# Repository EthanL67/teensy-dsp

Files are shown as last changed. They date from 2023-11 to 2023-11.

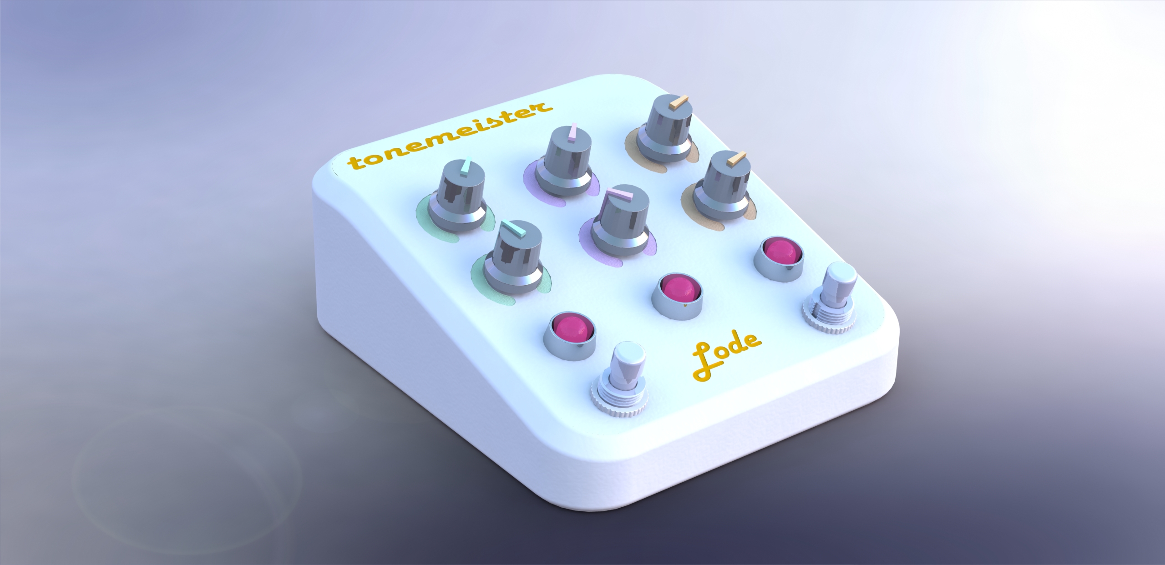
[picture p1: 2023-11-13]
renders/corner.JPG

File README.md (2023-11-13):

# teensy-dsp
Experimental pedal-format stereo effects processor using the Teensy 4.1 and Audio Shield. Hardware development currently in progress!

corner


My design goals are as follows:
-	Reprogrammable stereo multi-effects console
-	Accepts instrument-level and line-level audio inputs
-	Runs on common 9V guitar pedal power supplies
-	Implementations of common audio effects:
    -	Saturation/distortion, fuzz
    -	Phaser, vibrato, chorus
    -	Digital delay, tape delay emulation
    -	Studio-quality reverb

# BOM
- [Teensy 4.1 Microcontroller](https://www.pjrc.com/store/teensy41.html)
- [Teensy Audio Shield](https://www.pjrc.com/store/teensy3_audio.html)

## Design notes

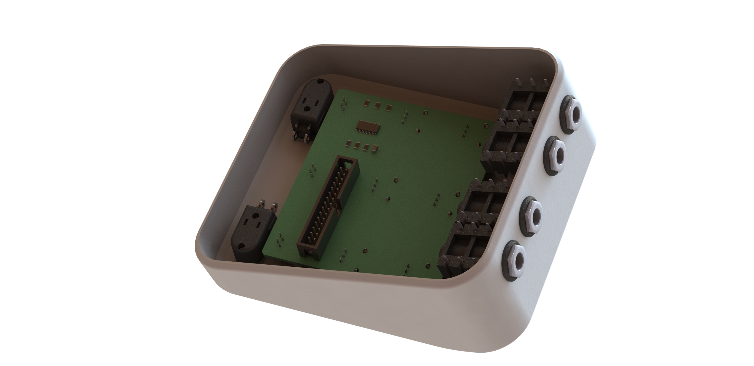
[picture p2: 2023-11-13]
renders/back.JPG

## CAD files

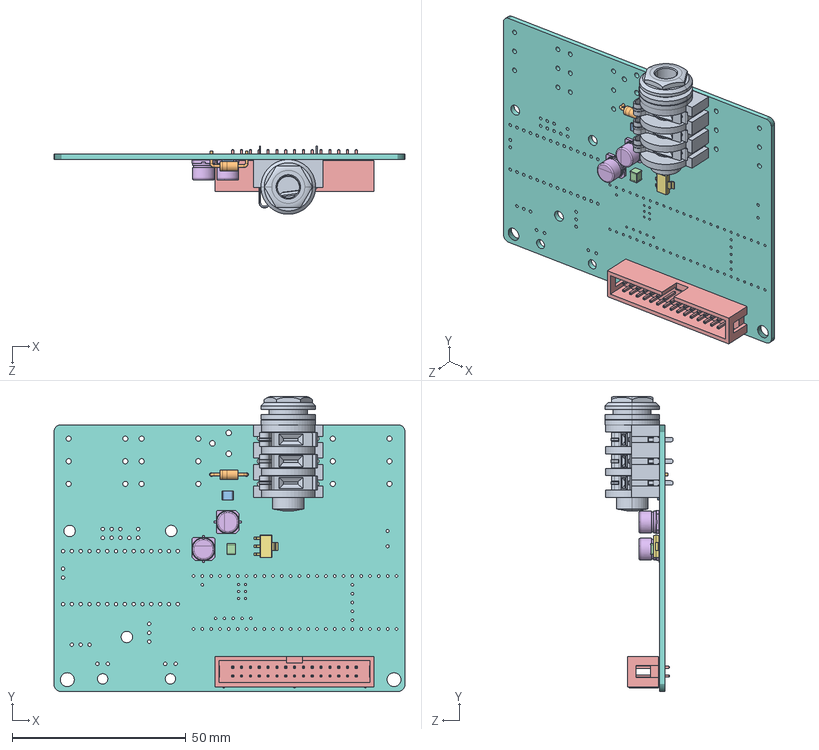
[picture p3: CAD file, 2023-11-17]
pcb/teensy-dsp/teensy-dsp-pcb.SLDASM
101.0 x 84.9 x 19.7 mm
AutoRecover Of COMPOUND.step.SLDPRT.swar
SOLID.step
SOLID-0.step
SOLID-1.step
SOLID-2.step
SOLID-3.step x 2
SOLID-4.step
AutoRecover Of PCB.step.SLDPRT.swar

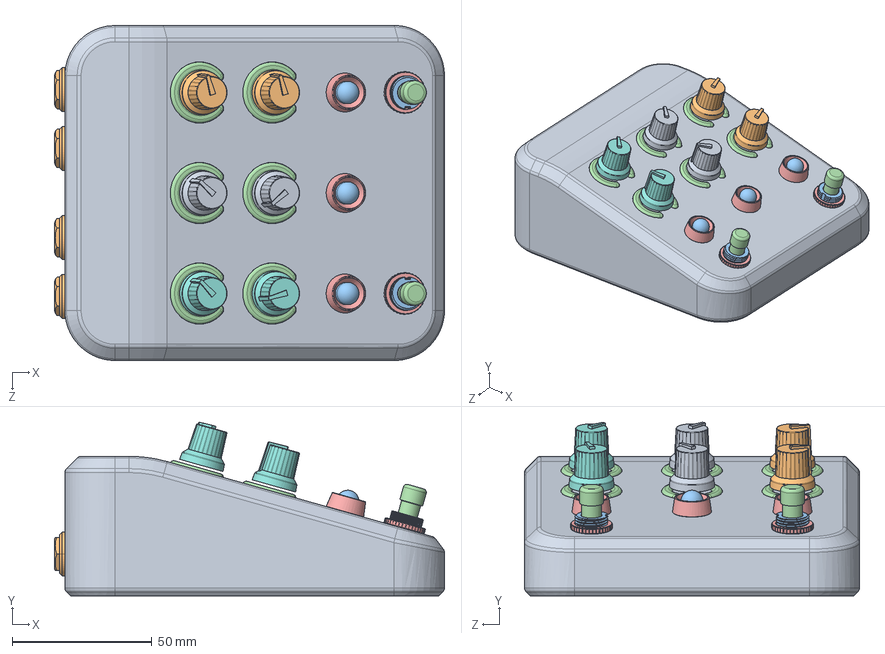
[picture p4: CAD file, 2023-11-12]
case/Case.SLDASM
139.7 x 62.2 x 120.0 mm
case-lid
ACJS-IH.STEP x 4
Momentary footswitch1.step x 2
Momentary footswitch6.step x 2
PLH-8 LED holder - body x 3
PLH-8 LED holder - spacer x 3
PLH-8 LED holder - nut x 3
CL170849BR x 2
CL170851BR x 2
CL170853BR x 2
LED-8mm x 3
knob-inlay x 6
M12x1 knurled thumb nut x 2

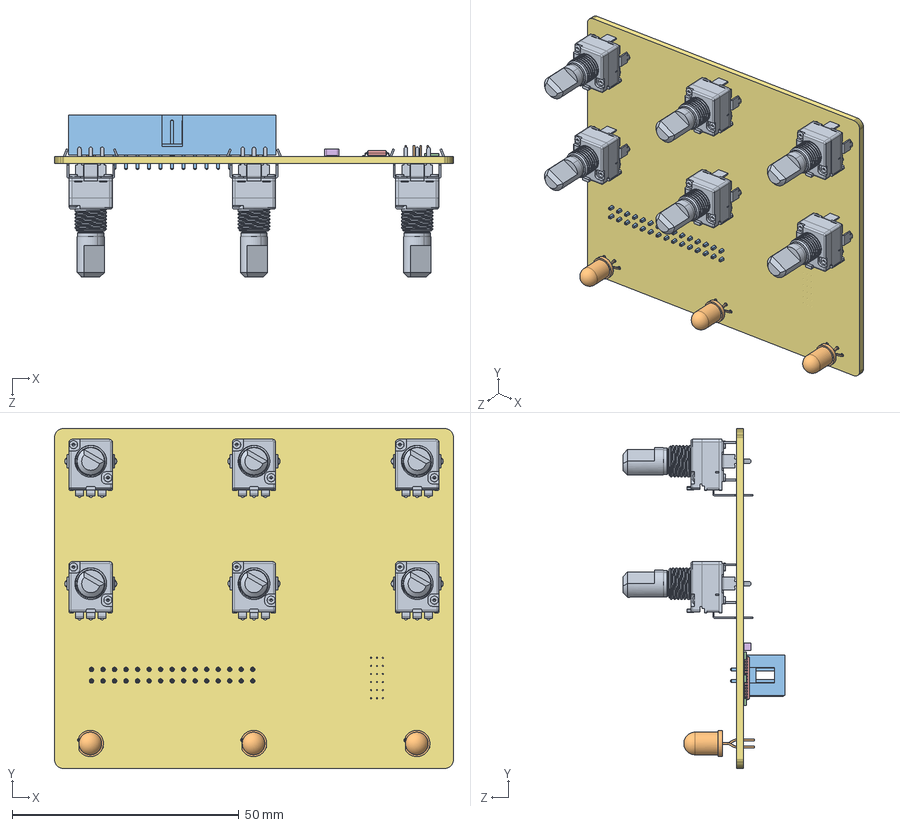
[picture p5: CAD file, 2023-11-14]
pcb/teensy-dsp/teensy-dsp-frontend/teensy-dsp-frontend.SLDASM
88.0 x 75.0 x 35.8 mm
COMPOUND.step x 6
SOLID.step x 3
SOLID-0.step
SOLID-1.step x 6
SOLID-2.step
SOLID-3.step
PCB.step

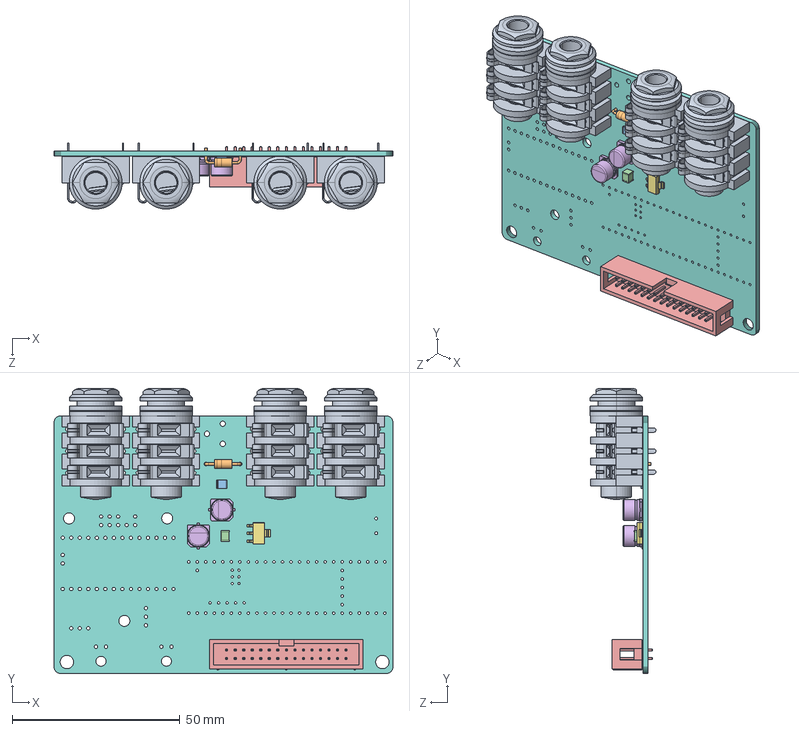
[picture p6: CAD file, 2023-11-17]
pcb/teensy-dsp/teensy-dsp.SLDASM
101.0 x 84.9 x 19.7 mm
COMPOUND.step x 4
SOLID.step
SOLID-0.step
SOLID-1.step
SOLID-2.step
SOLID-3.step x 2
SOLID-4.step
PCB.step

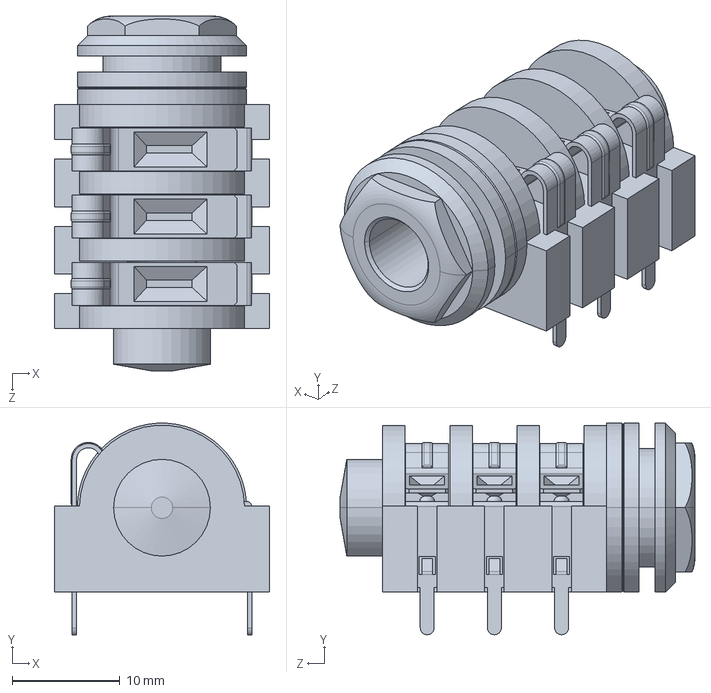
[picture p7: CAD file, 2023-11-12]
case/ACJS-IH--3DModel-STEP-56544.SLDASM
20.0 x 19.7 x 33.0 mm

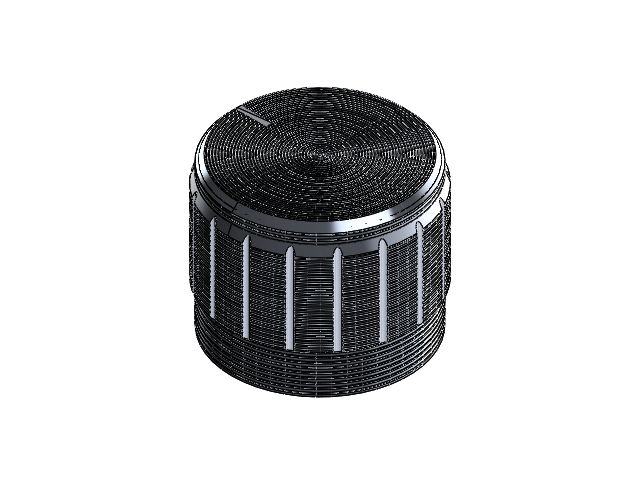
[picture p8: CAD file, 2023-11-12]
case/knob.SLDASM
__ 20 outtt.STEP
__ 20 innerrr.STEP

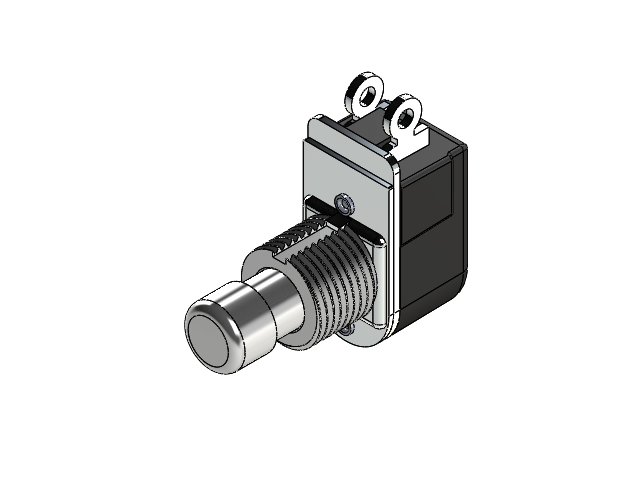
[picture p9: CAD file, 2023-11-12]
case/Momentary footswitch.step.SLDASM
Momentary footswitch1.step
Momentary footswitch2.step
Momentary footswitch3.step
Momentary footswitch4.step
Momentary footswitch5.step
Momentary footswitch6.step
Momentary footswitch7.step
Momentary footswitch8.step
Momentary footswitch9.step

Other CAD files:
pcb/teensy-dsp/teensy-dsp-frontend/IDC-Header_2x15_P2.54mm_Vertical.step.SLDASM
pcb/teensy-dsp/CP_Elec_6.3x5.9.step.SLDASM
pcb/teensy-dsp/IDC-Header_2x15_P2.54mm_Vertical.step.SLDASM
pcb/teensy-dsp/teensy-dsp-frontend/HTSSOP-28-1EP_4.4x9.7mm_P0.65mm_EP3.4x9.5mm.step.SLDASM
pcb/teensy-dsp/teensy-dsp-frontend/R_1206_3216Metric.step.SLDASM
pcb/teensy-dsp/teensy-dsp-frontend/C_1206_3216Metric.step.SLDASM
pcb/teensy-dsp/C_1210_3225Metric.step.SLDASM
pcb/teensy-dsp/teensy-dsp-frontend/P0915N-FC15AR50K.step.SLDASM
pcb/teensy-dsp/D_DO-41_SOD81_P10.16mm_Horizontal.step.SLDASM
pcb/teensy-dsp/R_1210_3225Metric.step.SLDASM
pcb/teensy-dsp/SOT-223.step.SLDASM
case/57GB5FX--3DModel-STEP-1.SLDPRT
case/CL170849BR.SLDPRT
case/CL170851BR.SLDPRT
case/CL170853BR.SLDPRT
case/LED-8mm.SLDPRT
case/M12x1 knurled thumb nut.SLDPRT
case/Momentary footswitch1.step.SLDPRT
case/Momentary footswitch2.step.SLDPRT
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

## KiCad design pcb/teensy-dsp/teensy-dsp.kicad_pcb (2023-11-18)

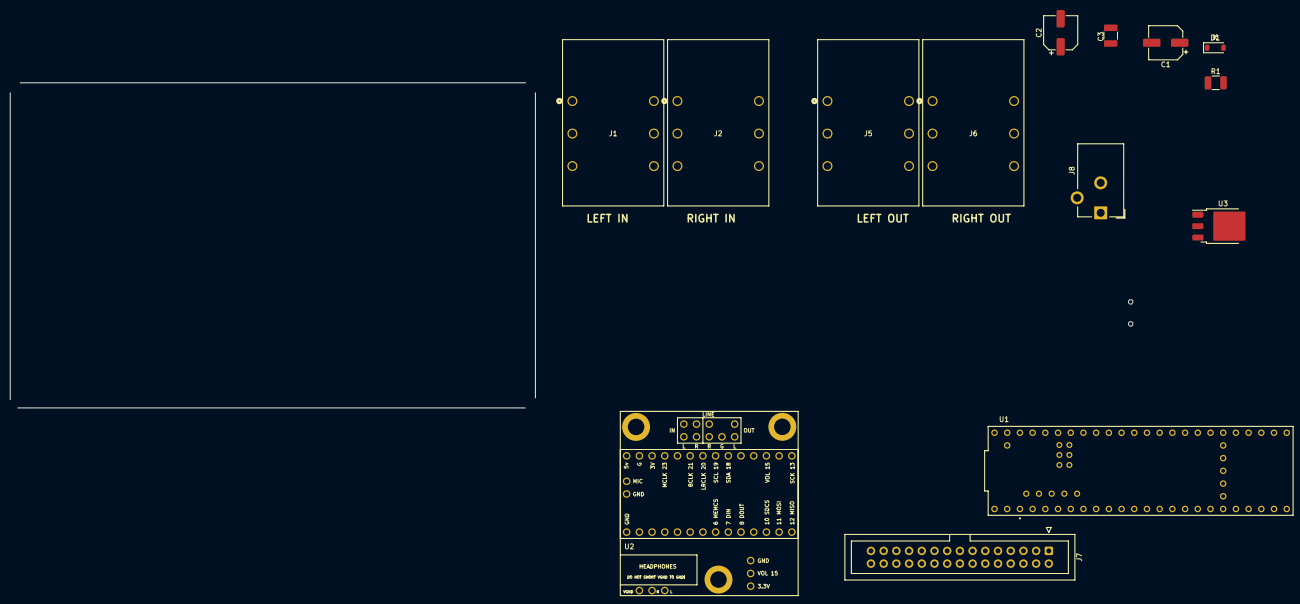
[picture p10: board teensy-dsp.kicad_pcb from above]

Board: 4 copper layers, 105.0 x 65.0 mm, 15 parts (1 on the bottom side), 37 nets, no tracks yet.

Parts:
C1, C2: 100u 16V; CP_Elec_6.3x5.9
C3: 100n 16V; C_1210_3225Metric_Pad1.33x2.70mm_HandSolder
D1: D; D_SOD-123
J1, J2, J5, J6: ACJS-IH; ACJS-IH_AMP
J7: Conn_02x15_Odd_Even; IDC-Header_2x15_P2.54mm_Vertical
J8: Barrel_Jack_Switch; BarrelJack_CUI_PJ-102AH_Horizontal
J9: USB_B_Mini; USB_Mini-B_Wuerth_65100516121_Horizontal
R1: 47R; R_1210_3225Metric_Pad1.30x2.65mm_HandSolder
U1: Teensy4.1; MODULE_DEV-16771
U2: Teensy4.0_AudioShield_REVD; 4.0audioshield
U3: LM7805_TO220; TO-252-3_TabPin2

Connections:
+3.3V: J7.3, U1.3.3V_1 (3.3V), U1.3.3V_2 (3.3V__1), U1.3.3V_3 (3.3V__2), U2.28 (3V)
+5V: C2.1, C3.1, U1.VIN, U3.3 (VO)
+9V: C1.1, J7.1, R1.2, U3.1 (VI)
Audio BCLK: U1.21 (A7), U2.25 (21_A7_RX5_BCLK1)
Audio DIN: U1.7 (RX2), U2.9 (7_RX2_OUT1A)
Audio DOUT: U1.8 (TX2), U2.10 (8_TX2_IN1)
Audio LRCLK: U1.20 (A6), U2.24 (20_A6_TX5_LRCLK1)
Audio MCLK: U1.23 (A9), U2.27 (23_A9_CRX1_MCLK1)
Audio MEMCS: U1.6 (OUT1D), U2.8 (6_OUT1D)
Audio MISO: U1.12 (MISO), U2.14 (12_MISO_MQSL)
Audio MOSI: U1.11 (MOSI), U2.13 (11_MOSI_CTX1)
Audio SCK: U1.13 (SCK), U2.17 (13_SCK_CRX1_LED)
Audio SCL: U1.19 (A5), U2.23 (19_A5_SCL0)
Audio SDA: U1.18 (A4), U2.22 (18_A4_SDA0)
Audio SDCS: U1.10 (CS1), U2.12 (10_CS_MQSR)
FSW_1: J7.7, U1.28 (RX7)
FSW_2: J7.5, U1.29 (TX7)
GND: C1.2, C2.2, C3.2, J1.R, J2.R, J5.R, J6.R, J7.2, J7.4, J7.6, J7.8, J7.10, J7.12, J7.14, J7.16, J7.18, J7.20, J7.22, J7.24, J7.26, J7.28, J7.30, J8.1, J9.5 (GND), U1.GND1 (GND), U1.GND2 (GND__1), U1.GND3 (GND__2), U1.GND4 (GND__3), U1.GND5 (GND__4), U1.USB_GND1 (USB_GND), U1.USB_GND2 (USB_GND__1), U2.1 (GND), U2.29 (GND), U2.32 (LINE_OUT_GND), U2.36 (LINE_IN_R_GND), U2.37 (LINE_IN_L_GND), U3.2 (GND)
L Line In: J1.T, U2.35 (LINE_IN_L)
L Line Out: J5.T, U2.31 (LINE_OUT_L)
LED_BLANK: J7.15, U1.2 (OUT2)
LED_GSCLK: J7.9, U1.5 (IN2)
LED_SCLK: J7.11, U1.4 (BCLK2)
LED_SIN: J7.17, U1.9 (OUT1C)
LED_XLAT: J7.13, U1.3 (LRCLK2)
unnamed: D1.2 (A), J8.2
unnamed: D1.1 (K), R1.1
unnamed: J9.3 (D+), U1.D+
unnamed: J9.2 (D-), U1.D-
POT_1: J7.19, U1.27 (A13)
POT_2: J7.21, U1.26 (A12)
POT_3: J7.23, U1.25 (A11)
POT_4: J7.25, U1.24 (A10)
POT_5: J7.27, U1.38 (A14)
POT_6: J7.29, U1.39 (A15)
R Line In: J2.T, U2.34 (LINE_IN_R)
R Line Out: J6.T, U2.33 (LINE_OUT_R)

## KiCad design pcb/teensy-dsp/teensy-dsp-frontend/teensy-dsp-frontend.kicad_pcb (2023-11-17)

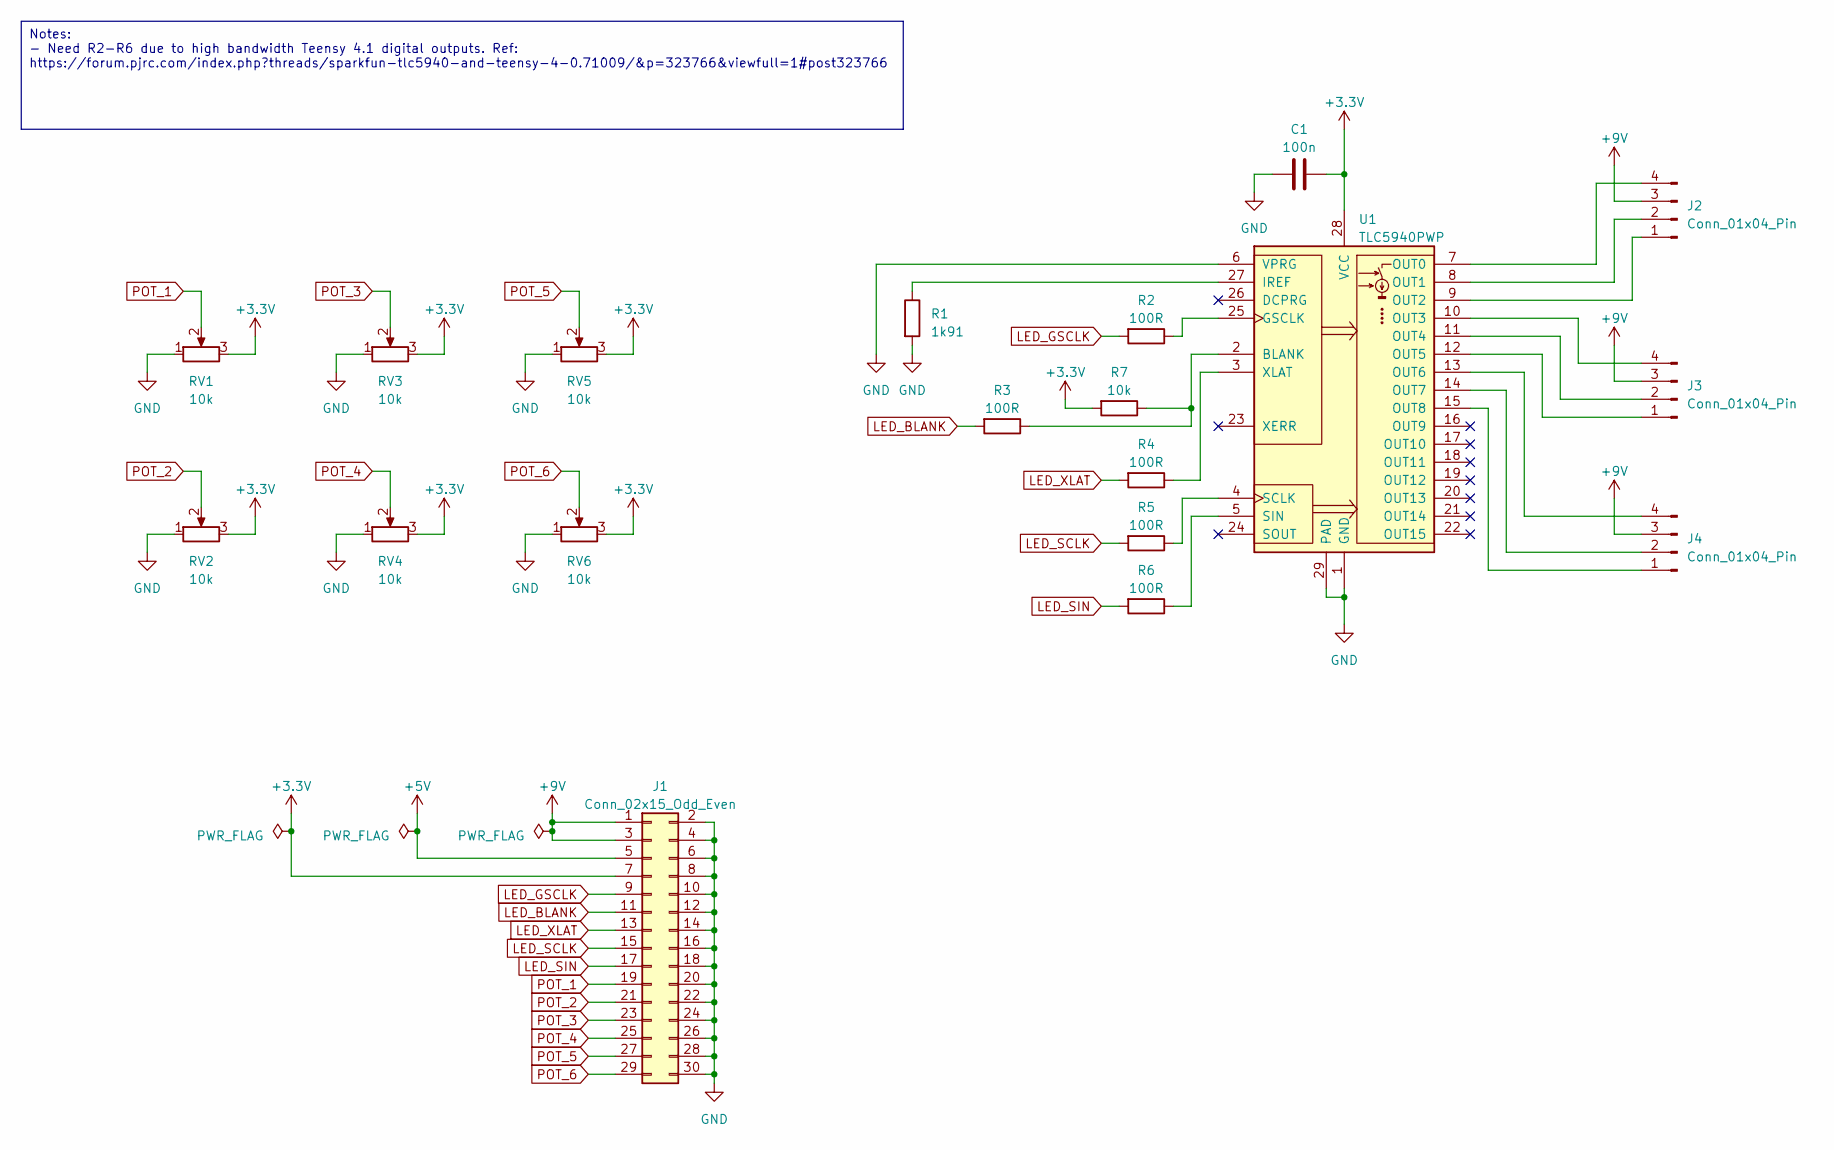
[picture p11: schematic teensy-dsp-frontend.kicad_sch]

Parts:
C1: 100n; C_1206_3216Metric_Pad1.33x1.80mm_HandSolder
J1: Conn_02x15_Odd_Even; IDC-Header_2x15_P2.54mm_Vertical
J2, J3, J4: Conn_01x04_Pin; PinHeader_1x04_P2.54mm_Horizontal
R1: 1k91; R_1206_3216Metric_Pad1.30x1.75mm_HandSolder
R2, R3, R4, R5, R6: 100R; R_1206_3216Metric_Pad1.30x1.75mm_HandSolder
R7: 10k; R_1206_3216Metric_Pad1.30x1.75mm_HandSolder
RV1, RV2, RV3, RV4, RV5, RV6: 10k; Potentiometer_TT_P0915N
U1: TLC5940PWP; HTSSOP-28-1EP_4.4x9.7mm_P0.65mm_EP3.4x9.5mm_Mask2.4x6.17mm_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

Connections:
+3.3V: C1.2, J1.7, R7.2, RV1.3, RV2.3, RV3.3, RV4.3, RV5.3, RV6.3, U1.28 (VCC)
+5V: J1.5
+9V: J1.1, J1.3, J2.3, J3.3, J4.3
GND: C1.1, J1.2, J1.4, J1.6, J1.8, J1.10, J1.12, J1.14, J1.16, J1.18, J1.20, J1.22, J1.24, J1.26, J1.28, J1.30, R1.2, RV1.1, RV2.1, RV3.1, RV4.1, RV5.1, RV6.1, U1.1 (GND), U1.6 (VPRG), U1.29 (PAD)
LED_BLANK: J1.11, R3.2
LED_GSCLK: J1.9, R2.2
LED_SCLK: J1.15, R5.2
LED_SIN: J1.17, R6.2
LED_XLAT: J1.13, R4.2
unnamed: J2.1, U1.9 (OUT2)
unnamed: J2.2, U1.8 (OUT1)
unnamed: J2.4, U1.7 (OUT0)
unnamed: J3.1, U1.12 (OUT5)
unnamed: J3.2, U1.11 (OUT4)
unnamed: J3.4, U1.10 (OUT3)
unnamed: J4.1, U1.15 (OUT8)
unnamed: J4.2, U1.14 (OUT7)
unnamed: J4.4, U1.13 (OUT6)
unnamed: R3.1, R7.1, U1.2 (BLANK)
unnamed: R2.1, U1.25 (GSCLK)
unnamed: R1.1, U1.27 (IREF)
unnamed: R5.1, U1.4 (SCLK)
unnamed: R6.1, U1.5 (SIN)
unnamed: R4.1, U1.3 (XLAT)
POT_1: J1.19, RV1.2
POT_2: J1.21, RV2.2
POT_3: J1.23, RV3.2
POT_4: J1.25, RV4.2
POT_5: J1.27, RV5.2
POT_6: J1.29, RV6.2

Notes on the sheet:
Notes: - Need R2-R6 due to high bandwidth Teensy 4.1 digital outputs. Ref: https://forum.pjrc.com/index.php?threads/sparkfun-tlc5940-and-teensy-4-0.71009/&p=323766&viewfull=1#post323766

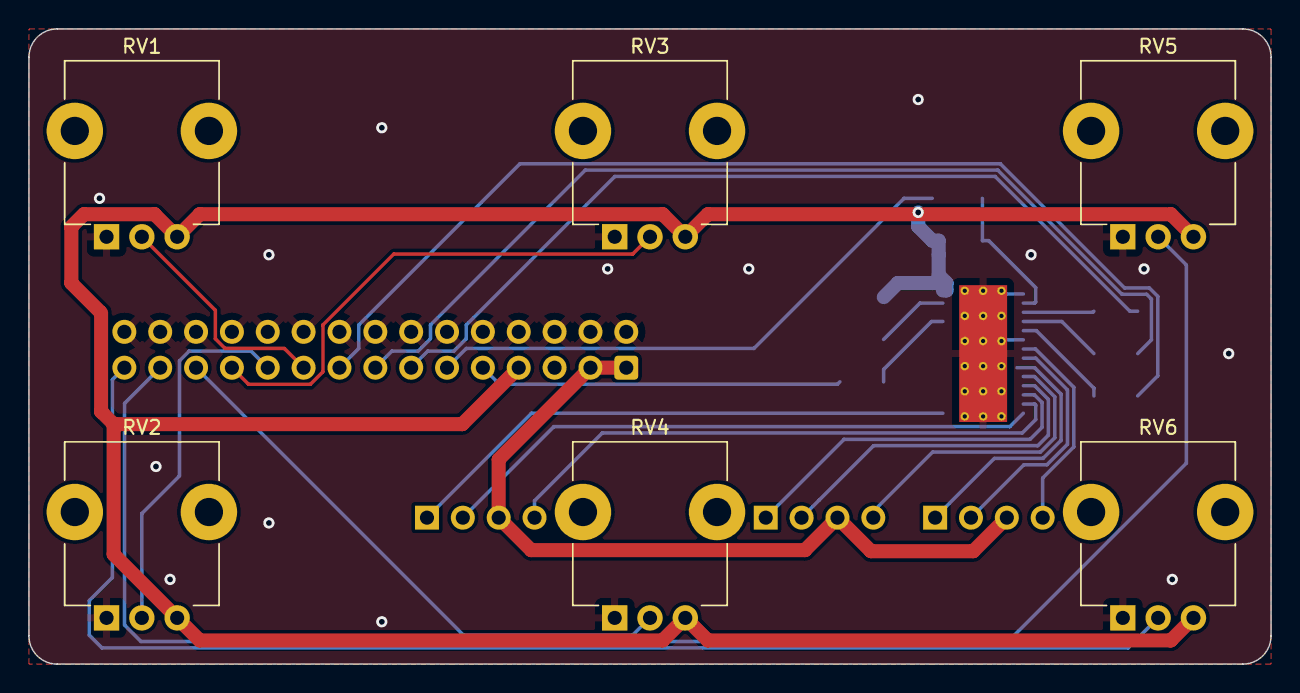
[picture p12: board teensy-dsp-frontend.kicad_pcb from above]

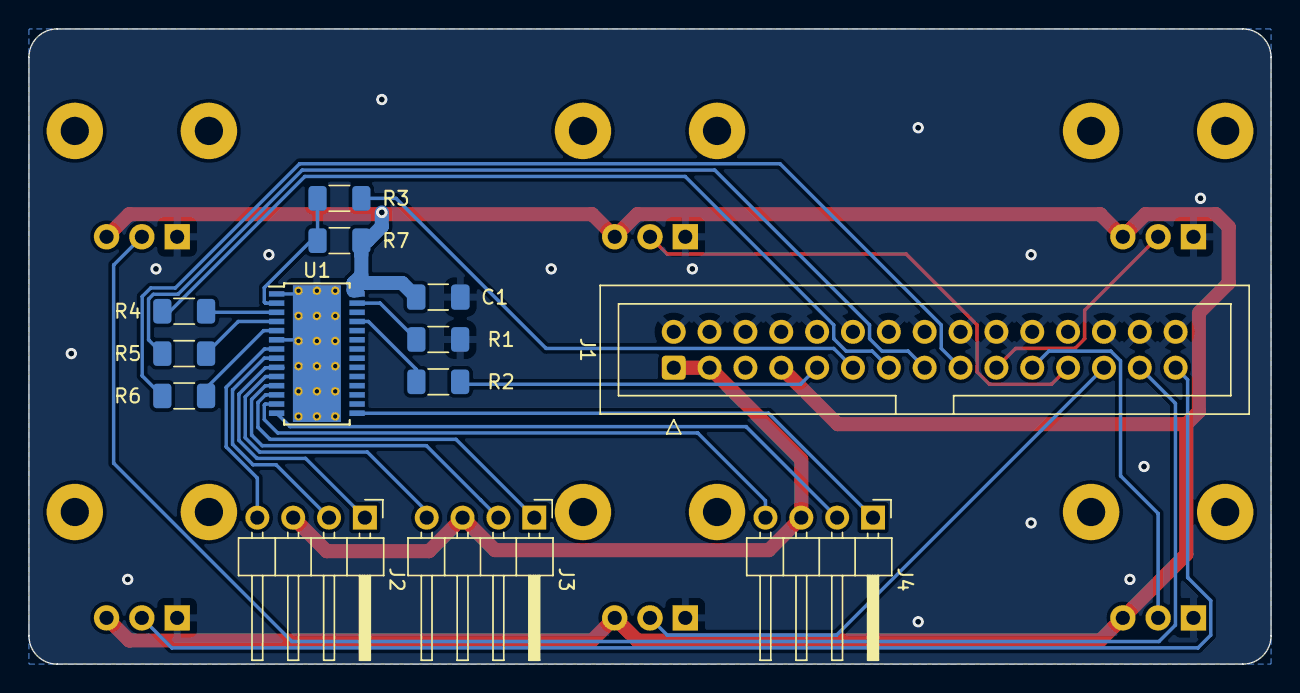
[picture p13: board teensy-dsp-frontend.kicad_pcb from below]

Board: 2 copper layers, 88.0 x 45.0 mm, 19 parts (13 on the bottom side), 29 nets.

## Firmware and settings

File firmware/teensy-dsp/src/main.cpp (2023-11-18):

// Freeverb - High quality reverb effect
//
//  Teensy 3.5 or higher is required to run this example
//
// The SD card may connect to different pins, depending on the
// hardware you are using.  Uncomment or configure the SD card
// pins to match your hardware.
//
// Data files to put on your SD card can be downloaded here:
//   http://www.pjrc.com/teensy/td_libs_AudioDataFiles.html
//
// This example code is in the public domain.

#include <Arduino.h>
#include <Audio.h>
#include <Wire.h>
#include <SPI.h>
#include <SD.h>
#include <SerialFlash.h>

// GUItool: begin automatically generated code
AudioInputI2S i2s_in;          // xy=582,483
AudioEffectFreeverb freeverb1; // xy=787,447
AudioMixer4 mixer1;            // xy=1006,477
AudioOutputI2S i2s_out;        // xy=1212.75,482
AudioConnection patchCord1(i2s_in, 0, freeverb1, 0);
AudioConnection patchCord2(i2s_in, 0, mixer1, 1);
AudioConnection patchCord3(freeverb1, 0, mixer1, 0);
AudioConnection patchCord4(mixer1, 0, i2s_out, 0);
AudioControlSGTL5000 sgtl5000_1; // xy=692.75,726
// GUItool: end automatically generated code

// Use these with the Teensy Audio Shield
#define SDCARD_CS_PIN 10
#define SDCARD_MOSI_PIN 7 // Teensy 4 ignores this, uses pin 11
#define SDCARD_SCK_PIN 14 // Teensy 4 ignores this, uses pin 13

// Use these with the Teensy 3.5 & 3.6 & 4.1 SD card
// #define SDCARD_CS_PIN    BUILTIN_SDCARD
// #define SDCARD_MOSI_PIN  11  // not actually used
// #define SDCARD_SCK_PIN   13  // not actually used

// Use these for the SD+Wiz820 or other adaptors
// #define SDCARD_CS_PIN    4
// #define SDCARD_MOSI_PIN  11
// #define SDCARD_SCK_PIN   13

#define POT1_PIN A10
#define POT2_PIN A11
#define POT3_PIN A12
#define POT4_PIN A13
#define POT5_PIN A14
#define POT6_PIN A15

void setup()
{
  Serial.begin(9600);

  pinMode(POT1_PIN, INPUT_DISABLE);
  pinMode(POT2_PIN, INPUT_DISABLE);
  pinMode(POT3_PIN, INPUT_DISABLE);
  pinMode(POT4_PIN, INPUT_DISABLE);
  pinMode(POT5_PIN, INPUT_DISABLE);
  pinMode(POT6_PIN, INPUT_DISABLE);

  // Audio connections require memory to work.  For more
  // detailed information, see the MemoryAndCpuUsage example
  AudioMemory(10);

  // Comment these out if not using the audio adaptor board.
  // This may wait forever if the SDA & SCL pins lack
  // pullup resistors
  sgtl5000_1.enable();
  sgtl5000_1.volume(0.8);

  SPI.setMOSI(SDCARD_MOSI_PIN);
  SPI.setSCK(SDCARD_SCK_PIN);
  if (!(SD.begin(SDCARD_CS_PIN)))
  {
    // stop here, but print a message repetitively
    while (1)
    {
      Serial.println("Unable to access the SD card");
      delay(500);
    }
  }

  mixer1.gain(0, 0.5);
  mixer1.gain(1, 0.5);
}

void loop()
{
  elapsedMillis msec;

  float knob_1 = 0.9;
  float knob_2 = 0.5;
  float knob_3 = 0.5;

  // Uncomment these lines to adjust parameters with analog inputs
  knob_1 = (float)analogRead(POT1_PIN) / 1023.0;
  knob_2 = (float)analogRead(POT2_PIN) / 1023.0;
  knob_3 = (float)analogRead(POT3_PIN) / 1023.0;

  mixer1.gain(0, knob_1);
  mixer1.gain(1, 1.0 - knob_1);

  freeverb1.roomsize(knob_2);
  freeverb1.damping(knob_3);

  if (msec > 250)
  {
    msec = 0;

    Serial.print("Reverb: mix=");
    Serial.print(knob_1 * 100.0);
    Serial.print("%, roomsize=");
    Serial.print(knob_2 * 100.0);
    Serial.print("%, damping=");
    Serial.print(knob_3 * 100.0);
    Serial.print("%, CPU Usage=");
    Serial.print(freeverb1.processorUsage());
    Serial.println("%");
  }
}

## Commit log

2023-11-11 added kicad project
    [teensy-dsp.kicad_pcb, teensy-dsp.kicad_sch]
2023-11-11 Added SolidWorks directory
    [case-lid.SLDPRT]
2023-11-12 updated solidworks and kicad files
    [io.kicad_sch, power.kicad_sch, teensy-dsp.kicad_pcb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]
2023-11-12 update kicad and solidworks
    [Case.SLDASM, case-lid.SLDPRT, front_panel.kicad_sch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]
2023-11-12 added initial render
    [Case.SLDASM, M12x1 knurled thumb nut.SLDPRT, case-lid.SLDPRT]
2023-11-13 update renders
    [case-lid.SLDPRT, nameplate-inlay.SLDPRT, teensy-dsp-frontend.kicad_pcb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]
2023-11-14 update pcb layout
    [io.kicad_sch, power.kicad_sch, teensy-dsp-frontend.SLDASM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]
2023-11-17 pcb and case updates
    [COMPOUND.step.SLDPRT, CP_Elec_6.3x5.9.step.SLDASM, C_1210_3225Metric.step.SLDASM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]
2023-11-18 case updates
    [C_1206_3216Metric.step.SLDASM, HTSSOP-28-1EP_4.4x9.7mm_P0.65mm_EP3.4x9.5mm.step.SLDASM, IDC-Header_2x15_P2.54mm_Vertical.step.SLDASM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]
